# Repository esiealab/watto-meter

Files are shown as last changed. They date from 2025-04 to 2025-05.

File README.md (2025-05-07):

# Watto-Meter

## Description

Watto-Meter is an open-source project designed to measure the power consumption of a device connected via USB-C. This project combines dedicated hardware and embedded software to provide the following features:

- **Power measurement**: Voltage, current, and power are measured.
- **Data logging**: Measurements are saved on an SD card in CSV format.
- **Web interface**: Data is accessible via a web page hosted on the device. The interface also allows:
  - Starting or stopping measurements.
  - Downloading or deleting recorded CSV files.
- **Web API**: A REST API enables remote control of the device and access to the data.

## Key Features

1. **Measurement**:
   - Voltage (Volts)
   - Current (mA)
   - Power (Watts)

2. **Data logging**:
   - Measurements are saved on an SD card in CSV format.

3. **User interface**:
   - An intuitive web interface to view data, configure the device, and manage recorded files.

4. **REST API**:
   - Remote control via HTTP endpoints to start/stop measurements, configure the device, or download files.

---

## Open-Source Hardware

The hardware for Watto-Meter is also open-source, created by [@Hyrla](https://github.com/Hyrla). All the files required to manufacture the PCB and assemble the device are available in the [`hardware/`](hardware/) folder.

### Hardware Image

Below is an image of the Watto-Meter hardware:

<p align="center">
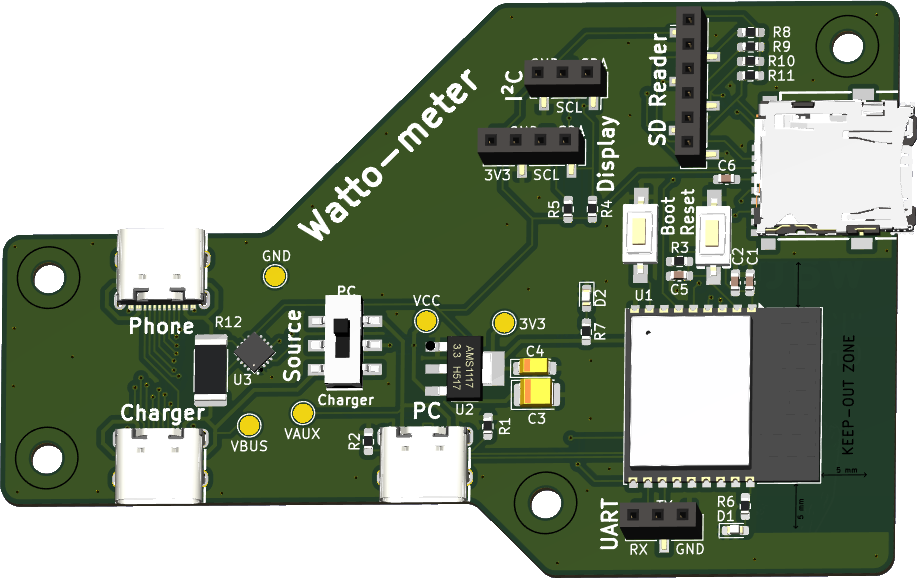
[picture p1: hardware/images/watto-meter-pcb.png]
</p>

---

## Software Development and Deployment

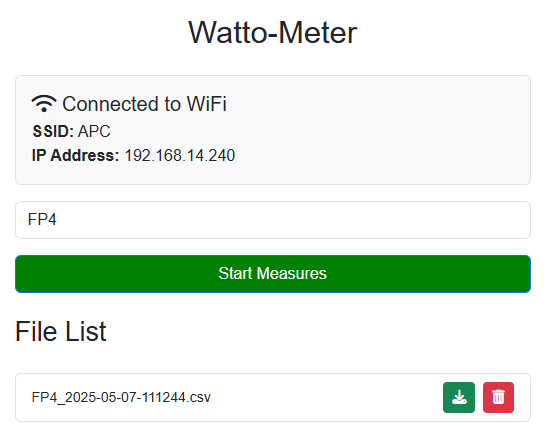
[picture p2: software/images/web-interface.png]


### Prerequisites

- [PlatformIO Core](https://docs.platformio.org/page/core.html)
- A Watto-Meter board (see the [`hardware/`](hardware/) folder)
- An SD card for data logging

### Instructions

1. **Clone the project**:
   ```bash
   git clone https://github.com/esiealab/watto-meter.git
   cd watto-meter/software
   ```

2. **Configure the project**:
   - Open the folder in PlatformIO.
   - Edit the [`platformio.ini`](software/platformio.ini) file if necessary and the [`WiFiConfig.h`](software/include/WiFiConfig.h) (WiFi SSID, password.).

3. **Build and upload the firmware**:
   ```bash
   pio run --target upload
   ```

4. **Upload folder [`data`](software/data/) to the filesystem**:
According to [this guide](https://randomnerdtutorials.com/esp32-vs-code-platformio-spiffs/):
   ```bash
   #Build the filesystem image
   pio run --target buildfs
   #Upload the filesystem image
   pio run --target uploadfs
   ```
Or you can open the PlatformIO menu and click on the following buttons:

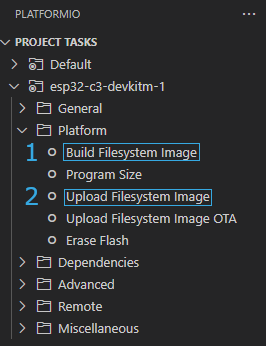
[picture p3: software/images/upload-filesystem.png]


---

## License

This project is licensed under the MIT License. You are free to use, modify, and distribute it, provided you retain the copyright notice.

---

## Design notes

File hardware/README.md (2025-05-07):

## Open-Source Hardware

The hardware for Watto-Meter is also open-source, created by [@Hyrla](https://github.com/Hyrla). All the files required to manufacture the PCB and assemble the device are available in the [`hardware/`](hardware/) folder.

### Hardware Image

Below is an image of the Watto-Meter hardware:



### Ordering the PCB on JLCPCB

To manufacture the PCB, you can use JLCPCB's fabrication service. Follow these steps:

1. **Download the Gerber files**:
   - The Gerber files required for fabrication are located in the [`hardware/`](hardware/) folder.

2. **Create an account on JLCPCB**:
   - Visit [https://jlcpcb.com](https://jlcpcb.com) and create an account.

3. **Upload the Gerber files**:
   - Click "Quote Now" and upload the Gerber files for the project.

4. **Configure fabrication options**:
   - Select your desired options (PCB color, thickness, etc.).

5. **Order components**:
   - If you want the PCB assembled, upload the Bill of Materials (BOM) and Component Placement List (CPL) files available in the [`hardware/production/`](hardware/production/) folder.

6. **Place the order**:
   - Confirm your order and wait for delivery.

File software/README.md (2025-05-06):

How to build PlatformIO based project
=====================================

1. [Install PlatformIO Core](https://docs.platformio.org/page/core.html)
2. Run these commands:

```shell
# Build project
$ pio run

# Upload firmware
$ pio run --target upload

# Clean build files
$ pio run --target clean
```

See https://randomnerdtutorials.com/esp32-vs-code-platformio-spiffs/ to send data folder to the ESP32.

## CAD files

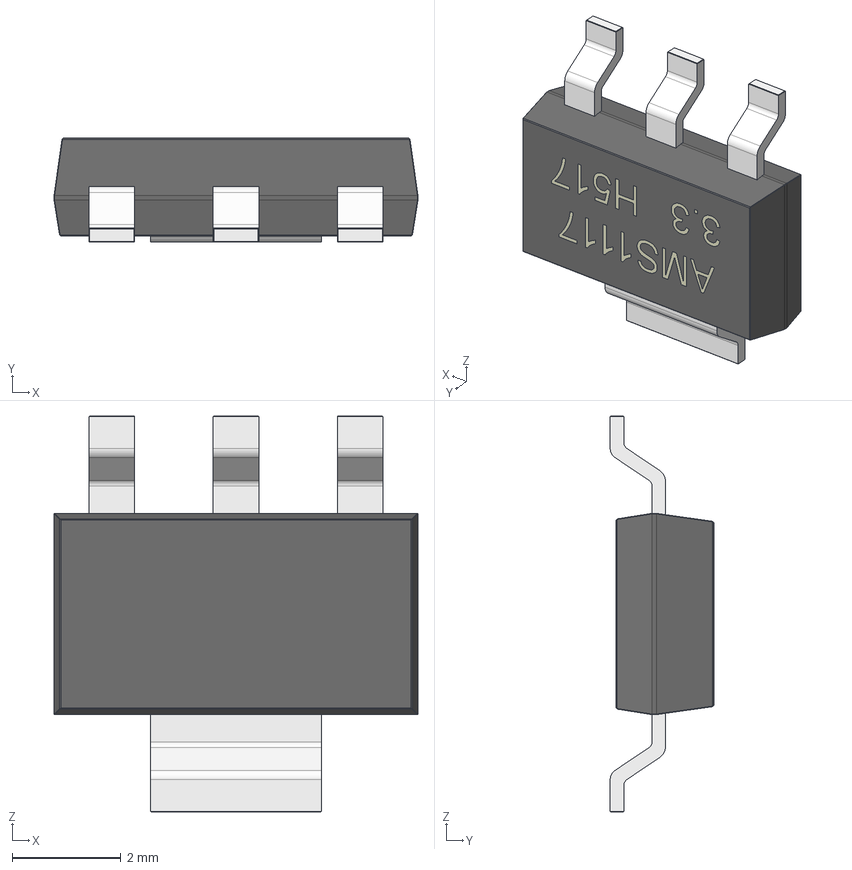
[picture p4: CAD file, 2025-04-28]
hardware/3D_models/AMS1117_3V3_axisY_by_NUKE13.step
6.71 x 1.91 x 7.30 mm

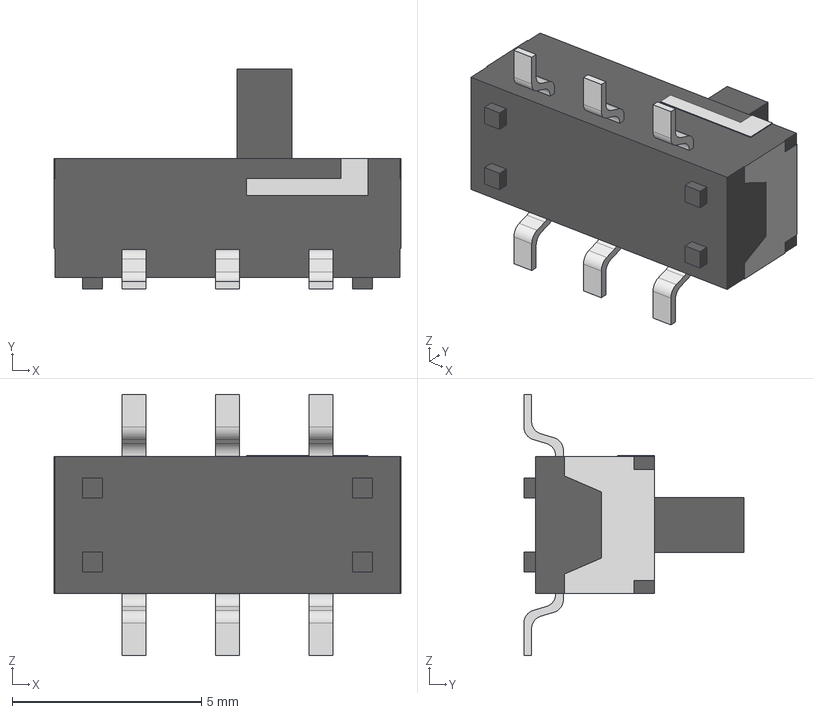
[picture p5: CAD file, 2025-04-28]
hardware/3D_models/Selector Switch - MSS22D18.stp
9.17 x 5.82 x 6.91 mm

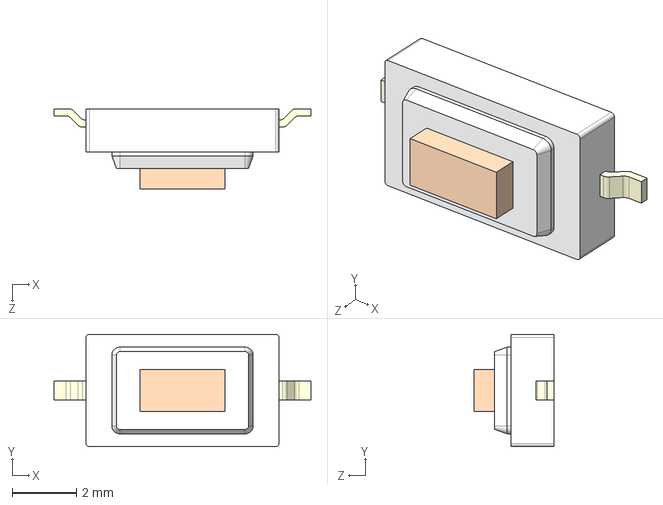
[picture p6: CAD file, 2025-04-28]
hardware/3D_models/G73 button.STEP
8.00 x 3.50 x 2.50 mm

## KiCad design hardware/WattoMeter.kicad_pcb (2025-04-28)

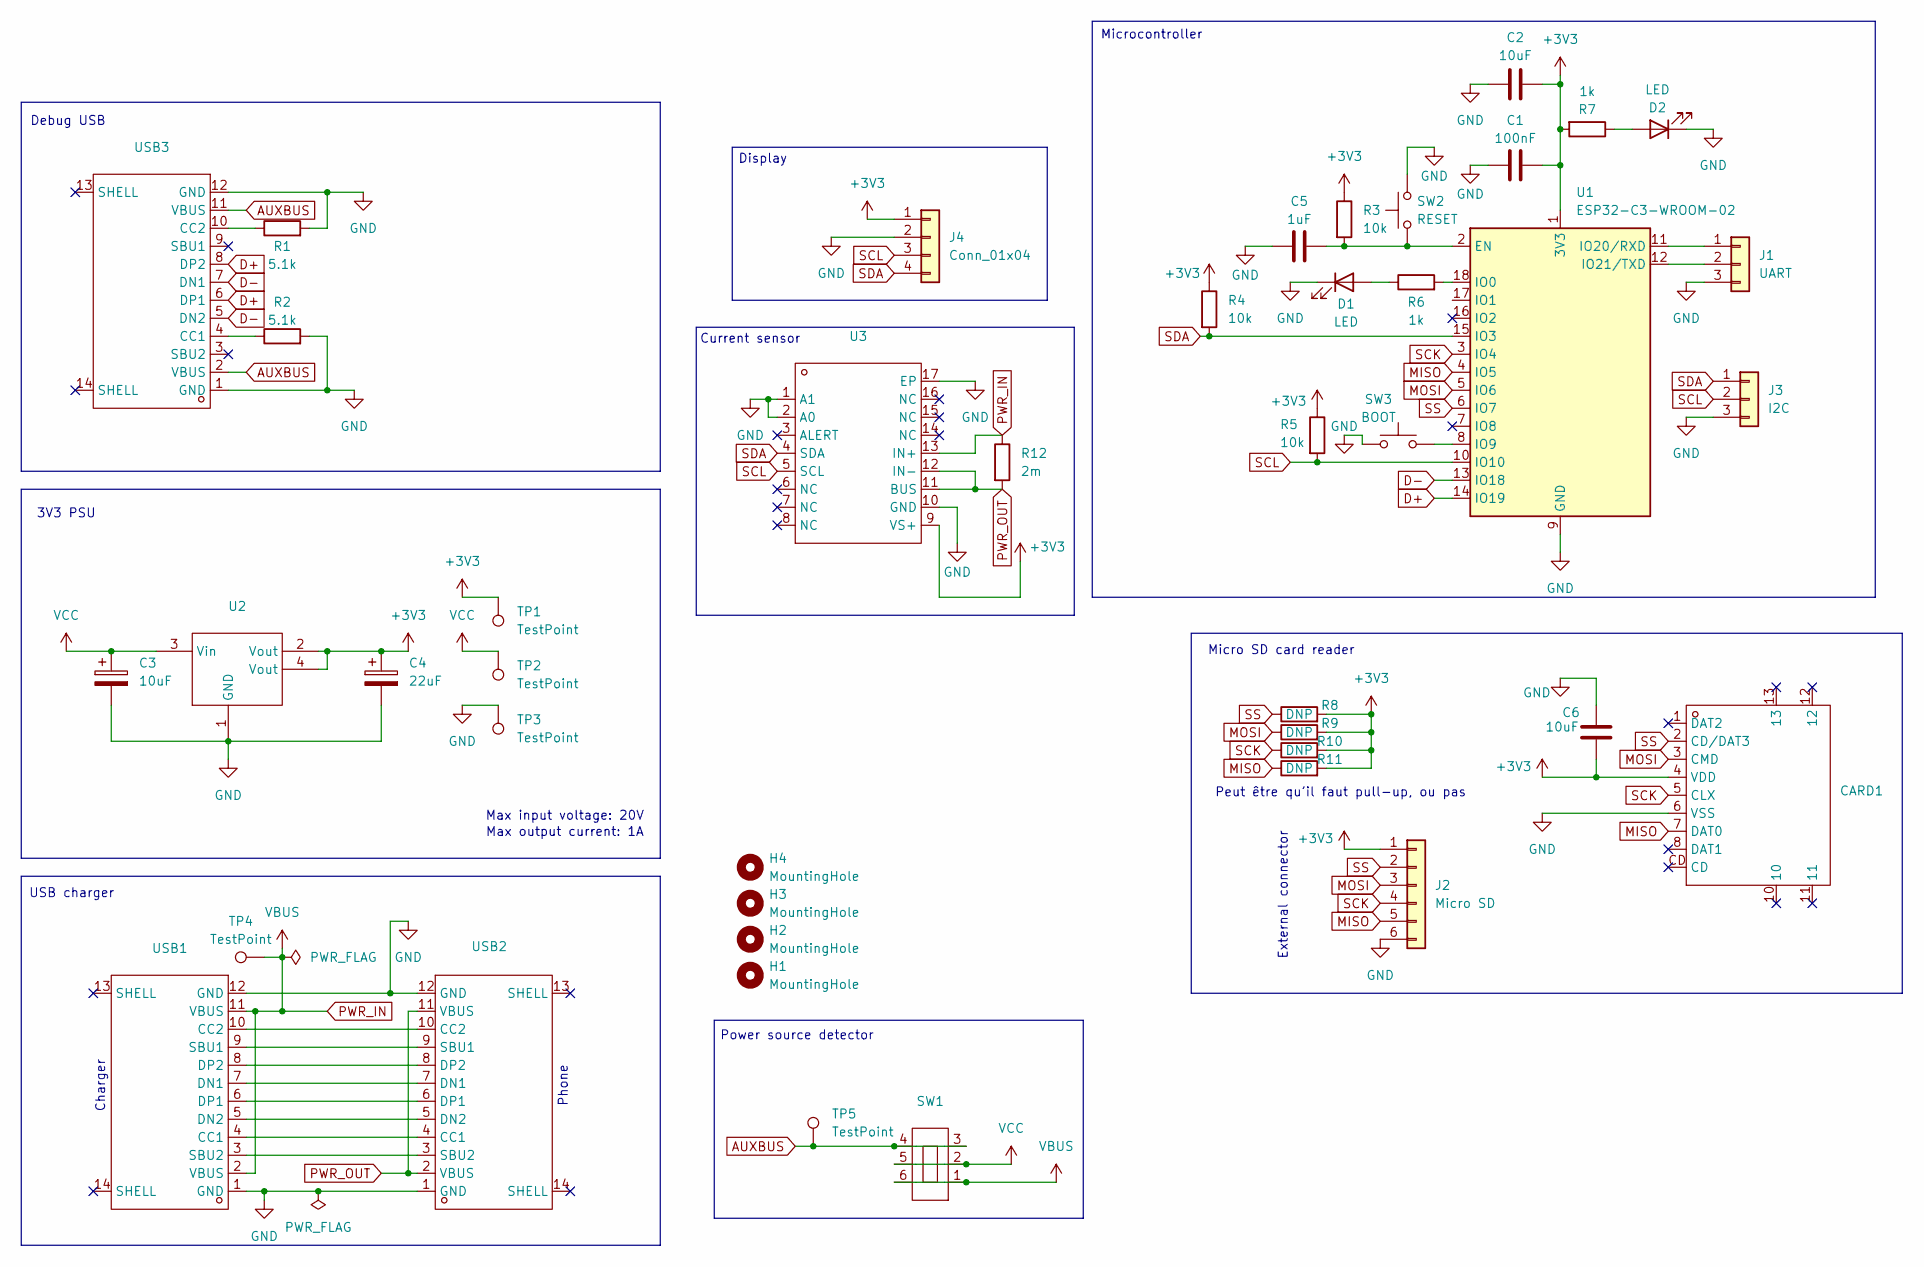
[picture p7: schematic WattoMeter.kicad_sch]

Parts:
C1: 100nF; C_0603_1608Metric_Pad1.08x0.95mm_HandSolder
C2, C6: 10uF; C_0603_1608Metric_Pad1.08x0.95mm_HandSolder
C3: 10uF; CP_EIA-3528-21_Kemet-B_Pad1.50x2.35mm_HandSolder
C4: 22uF; CP_EIA-3216-18_Kemet-A_Pad1.58x1.35mm_HandSolder
C5: 1uF; C_0603_1608Metric_Pad1.08x0.95mm_HandSolder
CARD1: TF-SMD_TF-PUSH; Manufacturer Part TF PUSH; LCSC Part Name 自弹式 MicroSD卡(TF卡) 卡座
D1, D2: LED; LED_0603_1608Metric_Pad1.05x0.95mm_HandSolder
H1, H2, H3, H4: MountingHole; MountingHole_3.2mm_M3
J1: UART; PinSocket_1x03_P2.54mm_Vertical_SMD_Pin1Right
J2: Micro SD; PinSocket_1x06_P2.54mm_Vertical_SMD_Pin1Left
J3: I2C; PinSocket_1x03_P2.54mm_Vertical_SMD_Pin1Right
J4: Conn_01x04; PinSocket_1x04_P2.54mm_Vertical_SMD_Pin1Right
R1, R2: 5.1k; R_0603_1608Metric_Pad0.98x0.95mm_HandSolder
R3, R4, R5: 10k; R_0603_1608Metric_Pad0.98x0.95mm_HandSolder
R6, R7: 1k; R_0603_1608Metric_Pad0.98x0.95mm_HandSolder
R8, R9, R10, R11: DNP; R_0603_1608Metric_Pad0.98x0.95mm_HandSolder
R12: 2m; R_2512_6332Metric_Pad1.40x3.35mm_HandSolder
SW1: SW-SMD_HOOYA_MS-22D17AG2.5-B; Manufacturer Part MS-22D17-G2; LCSC Part Name 微型拨动开关
SW2: RESET; SW-SMD_L6.0-W3.3-LS8.0
SW3: BOOT; SW-SMD_L6.0-W3.3-LS8.0
TP1, TP2, TP3, TP4, TP5: TestPoint; TestPoint_Pad_D2.0mm
U1: ESP32-C3-WROOM-02
U2: SOT-223-4_L6.5-W3.5-P2.30-LS7.0-BR; Manufacturer Part CJT1117B-3.3; LCSC Part Name 输入15V 输出3.3V 1A
U3: VQFN-16_L3.0-W3.0-P0.50-TL-EP; Manufacturer Part INA230AIRGTT; LCSC Part Name 高侧或低侧测量双向电流/功率监控器带I2C接口
USB1, USB2, USB3: USB-C-SMD_TYPE-C-6PIN-2MD-073; Manufacturer Part TYPE-C 16PIN 2MD(073); LCSC Part Name Type-C 母 卧贴

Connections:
+3V3: C1.1, C2.1, C4.1, C6.2, CARD1.4 (VDD), J2.1, J4.1, R3.1, R4.1, R5.1, R7.2, R8.2, R9.2, R10.2, R11.2, TP1.1, U1.1 (3V3), U2.2 (Vout), U2.4 (Vout), U3.9 (VS+)
AUXBUS: SW1.3, SW1.4, TP5.1, USB3.2 (VBUS), USB3.11 (VBUS)
D+: U1.14 (IO19), USB3.6 (DP1), USB3.8 (DP2)
D-: U1.13 (IO18), USB3.5 (DN2), USB3.7 (DN1)
GND: C1.2, C2.2, C3.2, C4.2, C5.2, C6.1, CARD1.6 (VSS), D1.1 (K), D2.1 (K), J1.3, J2.6, J3.3, J4.2, R1.2, R2.2, SW2.2, SW3.1, TP3.1, U1.9 (GND), U1.19 (GND), U2.1 (GND), U3.1 (A1), U3.2 (A0), U3.10 (GND), U3.17 (EP), USB1.1 (GND), USB1.12 (GND), USB2.1 (GND), USB2.12 (GND), USB3.1 (GND), USB3.12 (GND)
MISO: CARD1.7 (DAT0), J2.5, R11.1, U1.4 (IO5)
MOSI: CARD1.3 (CMD), J2.3, R9.1, U1.5 (IO6)
unnamed: D1.2 (A), R6.1
unnamed: D2.2 (A), R7.1
unnamed: J1.1, U1.11 (IO20/RXD)
unnamed: J1.2, U1.12 (IO21/TXD)
unnamed: C5.1, R3.2, SW2.1, U1.2 (EN)
unnamed: R6.2, U1.18 (IO0)
unnamed: SW3.2, U1.8 (IO9)
unnamed: USB1.4 (CC1), USB2.4 (CC1)
unnamed: USB1.10 (CC2), USB2.10 (CC2)
unnamed: USB1.7 (DN1), USB2.7 (DN1)
unnamed: USB1.5 (DN2), USB2.5 (DN2)
unnamed: USB1.6 (DP1), USB2.6 (DP1)
unnamed: USB1.8 (DP2), USB2.8 (DP2)
unnamed: USB1.9 (SBU1), USB2.9 (SBU1)
unnamed: USB1.3 (SBU2), USB2.3 (SBU2)
unnamed: R2.1, USB3.4 (CC1)
unnamed: R1.1, USB3.10 (CC2)
PWR_IN: R12.1, SW1.1, SW1.6, TP4.1, U3.13 (IN+), USB1.2 (VBUS), USB1.11 (VBUS)
PWR_OUT: R12.2, U3.11 (BUS), U3.12 (IN-), USB2.2 (VBUS), USB2.11 (VBUS)
SCK: CARD1.5 (CLX), J2.4, R10.1, U1.3 (IO4)
SCL: J3.2, J4.3, R5.2, U1.10 (IO10), U3.5 (SCL)
SDA: J3.1, J4.4, R4.2, U1.15 (IO3), U3.4 (SDA)
SS: CARD1.2 (CD/DAT3), J2.2, R8.1, U1.6 (IO7)
VCC: C3.1, SW1.2, SW1.5, TP2.1, U2.3 (Vin)

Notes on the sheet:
Max input voltage: 20V
Current sensor
Micro SD card reader
3V3 PSU
Display
Power source detector
Microcontroller
External connector
USB charger
Phone
Peut être qu'il faut pull-up, ou pas
Debug USB
Charger
Max output current: 1A

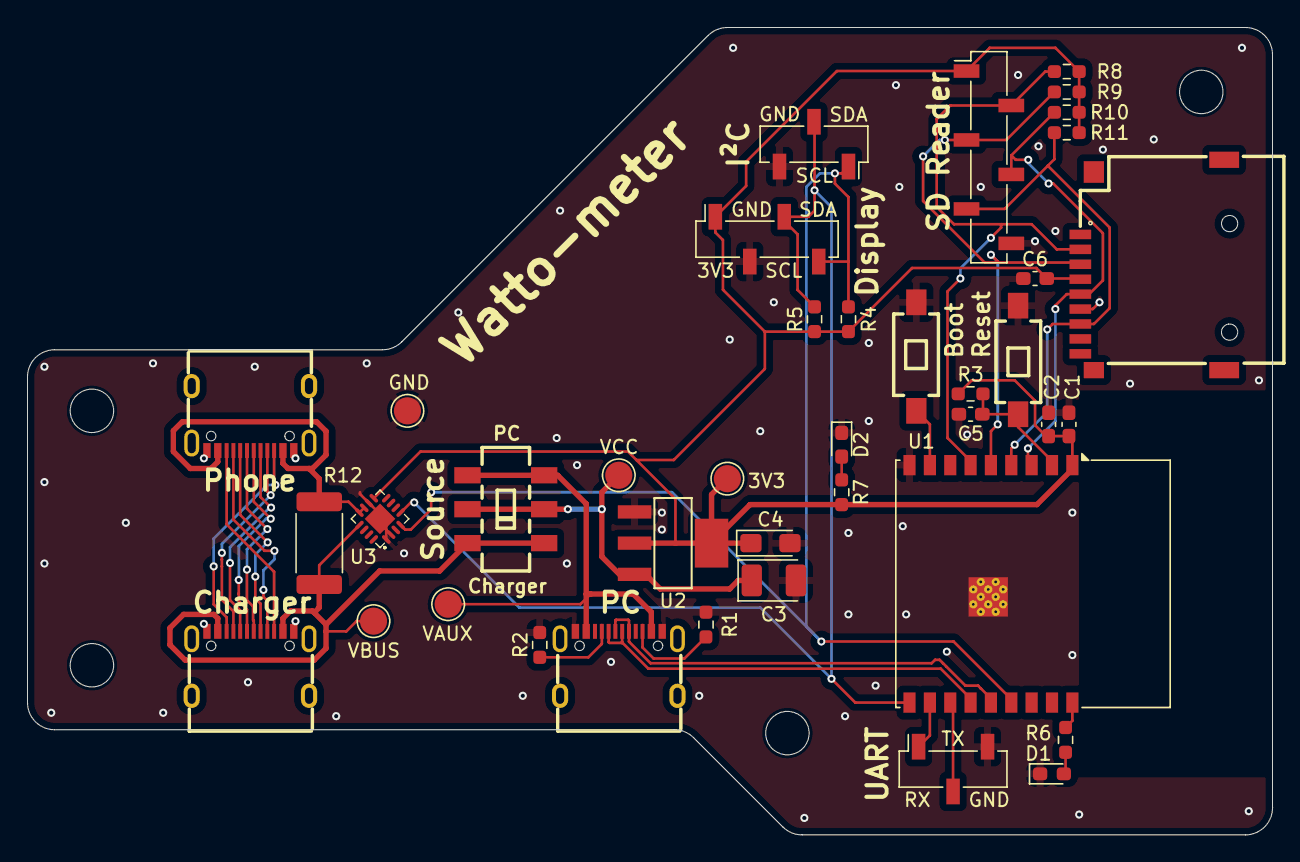
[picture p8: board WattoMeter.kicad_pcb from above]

Board: 2 copper layers, 91.8 x 59.5 mm, 43 parts (0 on the bottom side), 31 nets.

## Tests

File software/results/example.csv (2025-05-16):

Timestamp | BusVolts | CurrentMilliAmps | PowerWatts
2025-05-16 17:06:30.000 | 4.982 | 106.204 | 0.530
2025-05-16 17:06:30.003 | 4.982 | 106.204 | 0.530
2025-05-16 17:06:30.006 | 4.982 | 106.204 | 0.530
2025-05-16 17:06:30.009 | 4.982 | 106.204 | 0.530
2025-05-16 17:06:30.012 | 4.982 | 106.204 | 0.530
2025-05-16 17:06:30.015 | 4.982 | 106.204 | 0.530
2025-05-16 17:06:30.018 | 4.982 | 106.204 | 0.530
2025-05-16 17:06:30.021 | 4.982 | 106.204 | 0.649
2025-05-16 17:06:30.024 | 4.978 | 130.008 | 0.649
2025-05-16 17:06:30.027 | 4.978 | 130.008 | 0.649
2025-05-16 17:06:30.030 | 4.978 | 130.008 | 0.649
2025-05-16 17:06:30.033 | 4.978 | 130.008 | 0.649
2025-05-16 17:06:30.036 | 4.978 | 130.008 | 0.649
2025-05-16 17:06:30.039 | 4.978 | 130.008 | 0.649
2025-05-16 17:06:30.042 | 4.978 | 130.008 | 0.649
2025-05-16 17:06:30.045 | 4.978 | 130.008 | 0.649
2025-05-16 17:06:30.048 | 4.978 | 130.008 | 0.649
2025-05-16 17:06:30.051 | 4.978 | 130.008 | 0.649
2025-05-16 17:06:30.054 | 4.978 | 130.008 | 0.649
2025-05-16 17:06:30.057 | 4.978 | 147.556 | 0.732
2025-05-16 17:06:30.060 | 4.978 | 147.556 | 0.732
2025-05-16 17:06:30.063 | 4.978 | 147.556 | 0.732
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

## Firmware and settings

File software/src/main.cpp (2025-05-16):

#include <Arduino.h>

#include "DisplayManager.h"
#include "INAManager.h"
#include "SD.h"
#include "WiFiController.h"
// clang-format off
#include "APIManager.h"
// clang-format on

#define SCREEN_WIDTH 128
#define SCREEN_HEIGHT 64
#define SCREEN_I2C_ADDR 0x3C

#define SERIAL_SPEED 115200

#define INA_SHUNT_MICRO_OHM 2000                       // 2 mOhm
#define INA_MAXIMUM_AMPS 5                             // Expected max 5A
#define INA_BUS_CONVERSION_TIME 1                      // Conversion time in nanosecond for bus voltage
#define INA_SHUNT_CONVERSION_TIME 1                    // Conversion time in nanosecond for shunt voltage
#define INA_AVERAGING_COUNT 128                        // Averaging count (number of sample to average to compute a value)
#define INA_MEASUREMENT_MODE INA_MODE_CONTINUOUS_BOTH  // Measurement mode

#define I2C_SDA_PIN 3            // SDA pin
#define I2C_SCL_PIN 10           // SCL pin
#define I2C_CLOCK_SPEED 3400000  // I2C clock speed in Hz

#define TIMEZONE 1
#define DAYLIGHT_SAVING 1

#define QUEUE_SIZE 1000

// Frequency of the measure task
const int MEASURE_TASK_PERIOD = 3;
const int SD_TASK_PERIOD = MEASURE_TASK_PERIOD * 20;
const uint8_t NB_MEASURE_MAX_BEFORE_SD = SD_TASK_PERIOD * 2;  // Number of measures before writing to SD
void readI2CTask(void *parameter);
void writeSDTask(void *parameter);

// Frequency of the display update task (in milliseconds)
const int DISPLAY_TASK_PERIOD = 1000;
void updateDisplayTask(void *parameter);

void setupWiFiServer(void *parameter);

struct MeasurementData {
    float busVolts;
    float currentMilliAmps;
    float powerWatts;
    uint64_t time_us;
};

INAManager inaManager;
DisplayManager displayManager(SCREEN_WIDTH, SCREEN_HEIGHT, &Wire, -1);
WiFiController wifiController(TIMEZONE, DAYLIGHT_SAVING);
APIManager apiManager(80);
String fileName = "";
String deviceName = "";

QueueHandle_t measurementQueue;

void configModeCallback(WiFiManager *myWiFiManager) {
    Serial.println("WiFi Config mode");
    Serial.println(WiFi.softAPIP());
    Serial.println(myWiFiManager->getConfigPortalSSID());
}

void setup() {
    // Initialize serial communication and I2C
    Serial.begin(SERIAL_SPEED);
    Wire.begin(I2C_SDA_PIN, I2C_SCL_PIN, I2C_CLOCK_SPEED);

    // Initialize the SD card
    if (!SD.begin()) {
        Serial.println(F("SD card error"));
        while (1);
    }

    // Initialize the OLED display
    if (!displayManager.begin(SSD1306_SWITCHCAPVCC, SCREEN_I2C_ADDR)) {
        Serial.println(F("OLED display error"));
        while (1);
    }

    // Initialize the INA
    displayManager.showMessage(F("Searching INA..."));
    if (!inaManager.begin(INA_MAXIMUM_AMPS, INA_SHUNT_MICRO_OHM)) {
        Serial.println(F("No INA found, retrying..."));
        while (1);
    }
    inaManager.configure(INA_BUS_CONVERSION_TIME, INA_SHUNT_CONVERSION_TIME, INA_AVERAGING_COUNT, INA_MEASUREMENT_MODE);
    displayManager.showMessage(F("INA found."));

    // Create the queue for measurements
    measurementQueue = xQueueCreate(QUEUE_SIZE, sizeof(struct MeasurementData));
    if (measurementQueue == NULL) {
        Serial.println("Failed to create measurement queue");
        while (1);
    }

    // Start the I2C reading task
    xTaskCreatePinnedToCore(
        readI2CTask,      // Task function
        "Read I2C Task",  // Task name
        4096,             // Stack size
        NULL,             // Task parameter
        4,                // Task priority (higher priority)
        NULL,             // Task handle (not used here)
        1                 // Run on core 1
    );

    // Start the SD card writing task
    xTaskCreatePinnedToCore(
        writeSDTask,      // Task function
        "Write SD Task",  // Task name
        4096,             // Stack size
        NULL,             // Task parameter
        3,                // Task priority (lower priority)
        NULL,             // Task handle (not used here)
        1                 // Run on core 1
    );

    // Start the display update task
    xTaskCreatePinnedToCore(
        updateDisplayTask,      // Task function
        "Update Display Task",  // Task name
        4096,                   // Stack size
        NULL,                   // Task parameter
        2,                      // Task priority
        NULL,                   // Task handle (not used here)
        1                       // Run on core 1
    );

    // Create a task for initialization
    xTaskCreatePinnedToCore(
        setupWiFiServer,  // Task function
        "Init Task",      // Task name
        4096,             // Stack size
        NULL,             // Task parameter
        1,                // Task priority
        NULL,             // Task handle (not used here)
        1                 // Run on core 1
    );
}

void loop() {
}

void setupWiFiServer(void *parameter) {
    // Initialize WiFi and sync time
    displayManager.showMessage(F("Connect to WiFi..."));
    wifiController.connect(configModeCallback);
    displayManager.showMessage(F("Sync time..."));
    wifiController.syncTime();
    // Start the web server
    apiManager.begin();

    // Delete the task after initialization is complete
    vTaskDelete(NULL);
}

void updateDisplayTask(void *parameter) {
    TickType_t xLastWakeTime = xTaskGetTickCount();
    float busVolts, currentMilliAmps;
    uint64_t time_us;

    while (true) {
        displayManager.showMessage(wifiController.getInfosMessage(), true, 0, false, wifiicon);

        // Retrieve measurements for display
        time_us = wifiController.getCurrentTime_us();
        busVolts = inaManager.getBusVolts();
        currentMilliAmps = inaManager.getCurrentMilliAmps();

        UBaseType_t queueFillPercentage = (uxQueueMessagesWaiting(measurementQueue) * 100) / (uxQueueSpacesAvailable(measurementQueue) + uxQueueMessagesWaiting(measurementQueue));
        displayManager.showMessage(String(wifiController.formatCurrentTime(time_us, false, false) + "\nQueue: " + String(queueFillPercentage) + "%\n" +
                                          "Volt: " + String(busVolts, 2) + "V\n" +
                                          "Current: " + String(currentMilliAmps, 2) + "mA\n"),
                                   false, 3, true, NULL);

        // Delay before the next execution
        vTaskDelayUntil(&xLastWakeTime, pdMS_TO_TICKS(DISPLAY_TASK_PERIOD));
    }
}

void readI2CTask(void *parameter) {
    TickType_t xLastWakeTime = xTaskGetTickCount();
    struct MeasurementData measurement;

    while (true) {
        if (apiManager.isMeasuring()) {
            // Read data from INA
            measurement.time_us = wifiController.getCurrentTime_us();
            measurement.busVolts = inaManager.getBusVolts();
            measurement.currentMilliAmps = inaManager.getCurrentMilliAmps();
            measurement.powerWatts = inaManager.getPowerWatts();
            // Send data to the queue
            if (xQueueSend(measurementQueue, &measurement, 0) != pdPASS) {
                Serial.println("Measurement queue full, data dropped");
                vTaskDelay(pdMS_TO_TICKS(100));  // Wait before retrying
            }
        }

        // Delay before the next reading
        vTaskDelayUntil(&xLastWakeTime, pdMS_TO_TICKS(MEASURE_TASK_PERIOD));
    }
}

void writeSDTask(void *parameter) {
    File file;
    String csvBuffer;
    csvBuffer.reserve(50*NB_MEASURE_MAX_BEFORE_SD);
    uint16_t nbLines = 0;
    TickType_t xLastWakeTime = xTaskGetTickCount();
    struct MeasurementData measurement;
    bool measuringPrev = false;

    while (true) {
        bool measuring = apiManager.isMeasuring();

        // Start new file if needed
        if (measuring && !measuringPrev) {
            fileName = "/" + apiManager.getDeviceName() + "_" +
                       wifiController.formatCurrentTime(wifiController.getCurrentTime_us(), false, true) + ".csv";
            file = SD.open(fileName.c_str(), FILE_WRITE);
            if (file) {
                file.println("Timestamp,BusVolts,CurrentMilliAmps,PowerWatts");
                file.close();
                Serial.println("Measuring for device: " + apiManager.getDeviceName());
            }
            nbLines = 0;
            csvBuffer = "";
        }

        // If not measuring, reset state and close file if open
        if (!measuring) {
            fileName = "";
            measuringPrev = false;
            vTaskDelayUntil(&xLastWakeTime, pdMS_TO_TICKS(SD_TASK_PERIOD));
            continue;
        }

        // Read as many measurements as possible up to NB_MEASURE_MAX_BEFORE_SD
        nbLines = 0;
        csvBuffer = "";
        while (nbLines < NB_MEASURE_MAX_BEFORE_SD && xQueueReceive(measurementQueue, &measurement, 0) == pdPASS) {
            csvBuffer += String(wifiController.formatCurrentTime(measurement.time_us, true, false) + "," +
                                String(measurement.busVolts, 3) + "," +
                                String(measurement.currentMilliAmps, 3) + "," +
                                String(measurement.powerWatts, 3) + "\n");
            nbLines++;
        }

        // Write buffer if there is data
        if (nbLines > 0 && fileName != "") {
            file = SD.open(fileName.c_str(), FILE_APPEND);
            if (file) {
                file.print(csvBuffer);
                file.close();
            }
        }

        measuringPrev = measuring;
        vTaskDelayUntil(&xLastWakeTime, pdMS_TO_TICKS(SD_TASK_PERIOD));
    }
}

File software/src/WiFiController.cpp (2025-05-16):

#include "WiFiController.h"

WiFiController::WiFiController(long timezone, byte daysavetime)
    : timezone(timezone), daysavetime(daysavetime) {
    uniqueHostname = "WM-" + String((uint32_t)ESP.getEfuseMac(), HEX);
    uniqueHostname.toUpperCase();
    wifiManager.setHostname(uniqueHostname.c_str());

    wifiManager.setConfigPortalBlocking(true);
    // wifiManager.setConfigPortalTimeout(30);  // Set timeout to 30 seconds
}

void WiFiController::connect(void (*configModeCallback)(WiFiManager *)) {
    if (configModeCallback != NULL) {
        wifiManager.setAPCallback(configModeCallback);
    } else {
        wifiManager.setAPCallback([this](WiFiManager *myWiFiManager) {
            Serial.println("WiFi Config mode");
            Serial.println(WiFi.softAPIP());
            Serial.println(myWiFiManager->getConfigPortalSSID());
            Serial.println("Please connect to the WiFi network and open the config portal.");
        });
    }

    wifiManager.autoConnect(uniqueHostname.c_str(), NULL);
    Serial.printf("WiFi connected to %s\n", getSSID());
    Serial.printf("IP address: %s\n", getIPAddress());
    Serial.printf("Hostname: %s\n", getHostname());
}

void WiFiController::syncTime() {
    configTime(3600 * timezone, daysavetime * 3600, "pool.ntp.org", "time.nist.gov");
    struct tm timeinfo;    
    if (!getLocalTime(&timeinfo)) {
        Serial.println("Failed to obtain time");
        return;
    }
    Serial.printf("Time synchronized: %d-%02d-%02d %02d:%02d:%02d\n",
                  timeinfo.tm_year + 1900, timeinfo.tm_mon + 1, timeinfo.tm_mday,
                  timeinfo.tm_hour, timeinfo.tm_min, timeinfo.tm_sec);
}

uint64_t WiFiController::getCurrentTime_us() {
    struct timeval tv_now;
    gettimeofday(&tv_now, NULL);
    uint64_t time_us = (uint64_t)tv_now.tv_sec * 1000000L + (uint64_t)tv_now.tv_usec;
    return time_us;
}

String WiFiController::formatCurrentTime(uint64_t time_us, bool millisec, bool shortFormat) {
    char buffer[24];
    struct tm timeinfo;
    uint16_t milliseconds = 0;

    // Convert microseconds to seconds and get the timeinfo
    time_t seconds = time_us / 1000000;
    localtime_r(&seconds, &timeinfo);
    if (millisec) {
        milliseconds = time_us % 1000000 / 1000;
    }

    if (shortFormat) {
        sprintf(buffer, "%d-%02d-%02d-%02d%02d%02d",
                timeinfo.tm_year + 1900, timeinfo.tm_mon + 1, timeinfo.tm_mday,
                timeinfo.tm_hour, timeinfo.tm_min, timeinfo.tm_sec);
    } else if (millisec) {
        sprintf(buffer, "%d-%02d-%02d %02d:%02d:%02d.%03d",
                timeinfo.tm_year + 1900, timeinfo.tm_mon + 1, timeinfo.tm_mday,
                timeinfo.tm_hour, timeinfo.tm_min, timeinfo.tm_sec, milliseconds);
    } else {
        sprintf(buffer, "%d-%02d-%02d %02d:%02d:%02d",
                timeinfo.tm_year + 1900, timeinfo.tm_mon + 1, timeinfo.tm_mday,
                timeinfo.tm_hour, timeinfo.tm_min, timeinfo.tm_sec);
    }
    return String(buffer);
}

String WiFiController::getSSID() {
    return WiFi.SSID();
}

String WiFiController::getIPAddress() {
    return WiFi.localIP().toString();
}

String WiFiController::getHostname() {
    return WiFi.getHostname();
}

bool WiFiController::isConnected() {
    return WiFi.status() == WL_CONNECTED;
}

bool WiFiController::isConfigMode() {
    return wifiManager.getConfigPortalActive();
}

String WiFiController::getInfosMessage() {
    String info;
    if (!isConfigMode()) {
        info = getSSID() + "\n";
        info += getIPAddress() + "\n";
        info += getHostname() + "\n";
    } else {
        info = WiFi.softAPSSID() + " (AP)\n";
        info += WiFi.softAPIP().toString() + "\n";
        info += "Please configure.\n";
    }
    return info;
}

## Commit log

2025-04-28 First version, created by @Hyrla
    [AMS1117_3V3_axisY_by_NUKE13.step, G73 button.STEP, Selector Switch - MSS22D18.stp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]
2025-05-07 Add Watto-Meter zip file for PCB production
2025-05-07 Add "device" parameter to /startMeasures and add endpoint to list files in JSON
2025-05-14 Remove SDManager and related functionality; integrate SD card handling directly in main application logic. Separate I2C reading and SD writing to increase the maximum frequency of reading.
2025-05-15 Update formatCurrentTime method to include milliseconds parameter; adjust related time formatting logic in WiFiController and main application
2025-05-15 - Refactor measurement data structure: add powerWatts field and update related CSV logging in writeSDTask - Change INA parameter to request new conversion each microsecond and a value after 128 conve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
2025-05-16 - Refactor WiFiController: update time handling methods to use microseconds and adjust related logic in main application - Correct error using a global measurement variable
    [WiFiController.cpp, main.cpp]
2025-05-16 Add example to read and display data
    [example.csv]
